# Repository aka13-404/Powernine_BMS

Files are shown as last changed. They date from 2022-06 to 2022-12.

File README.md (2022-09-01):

# Powernine BMS
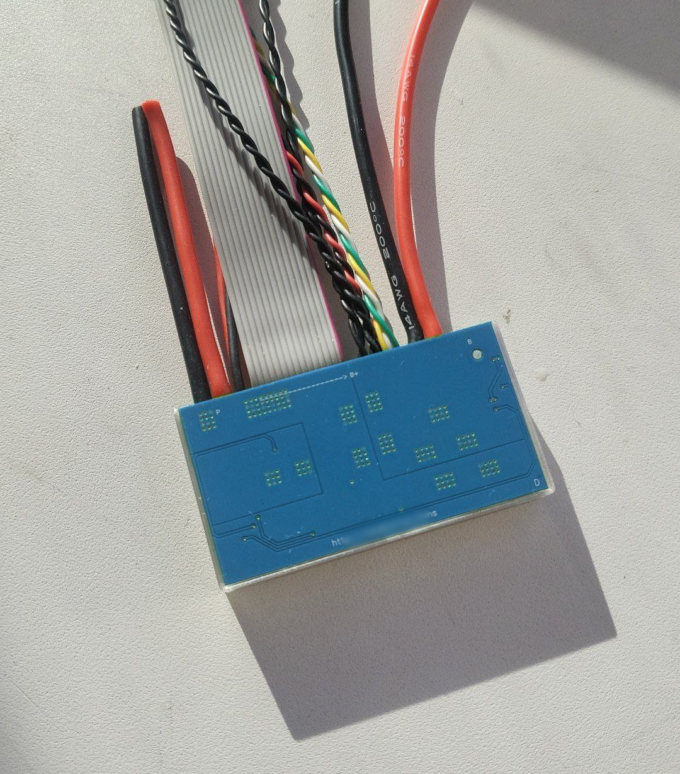
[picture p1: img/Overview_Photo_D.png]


This repository is dedicated to the documentation of the Powernine BMS project by SurgeSPB. 

The repository is split in two parts:
1. **[Hardware](Hardware)**
	The BMS is now out for a quite a long time, so multiple revisions exist. In this folder there are informations on individual parameters and differences of the different revisions and their parameters.
	It also contains information on what FW-versions are available
	**Never flash firmware other than noted**
2. **[Software](Software)**
	All existing BMS support configuration and firmware updating via bluetooth.
	The folder contains:
	  + The configuration tool used for the BMS, PowerNine
	  + Documentation on options available in Powernine, and how to use them
	  + Available firmwares to be used for different BMS revisions

## Features

_Current bms revision is **D**_.

|Parameter|Value|
| :--- |---:|
|Physical dimensions|65x35 mm|
|Peak discharge current|60 A|
|Max charge current|6 A|
|Cell balance current| 35 mA|
|Sections balanced at the same time | max 3|
|Balancing algorithm type|passive, 24/7 if no load is detected

This is a custom BMS, based on the stm G031 series. 
Its main feature is the **full support of the Ninebot/Xiaomi communication protocol**. 
It has a very small formfactor, and can deliver up to 60A peak current.
It's highly configurable, and can be configured according to the specific user scenario.
It is also possible to use it in stand-alone mode should you decide to ditch the ninebot ecosystem. 

## Where to buy

If you live in the eastern hemisphere, reach out directly to [Surge](https://t.me/SurgeSPB). 
If you live in Europe, reach out to [AK](https://t.me/aka13).

Please understand, that with current logistical limitations availability is limited and stock goes very quickly. 

## [Quick Setup](/Software/quick_setup.md)
There is a short manual on how to connect and setup the BMS, if you don't want to read the full documentation [here](/Software/quick_setup.md).

## Issues and questions

If you think something is missing/should be fixed in the documentation, or have suggestions, open an issue on github.

If you understand russian, want to discuss stuff, or get tips on the installation, you can join the [official group](https://t.me/ninebotfun). 
If you speak german or english, you can join the european group (coming soon).

## Disclaimer
Please remember, li-ion battaries are no joke. You should have an understanding on what you are doing, and why you are doing it. No BMS in the world is going to save you, if you don't know what you are doing.

Ride safe and obey local laws.

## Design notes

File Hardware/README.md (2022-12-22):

Please select the bms version you have/are interested in from the filelist on top.
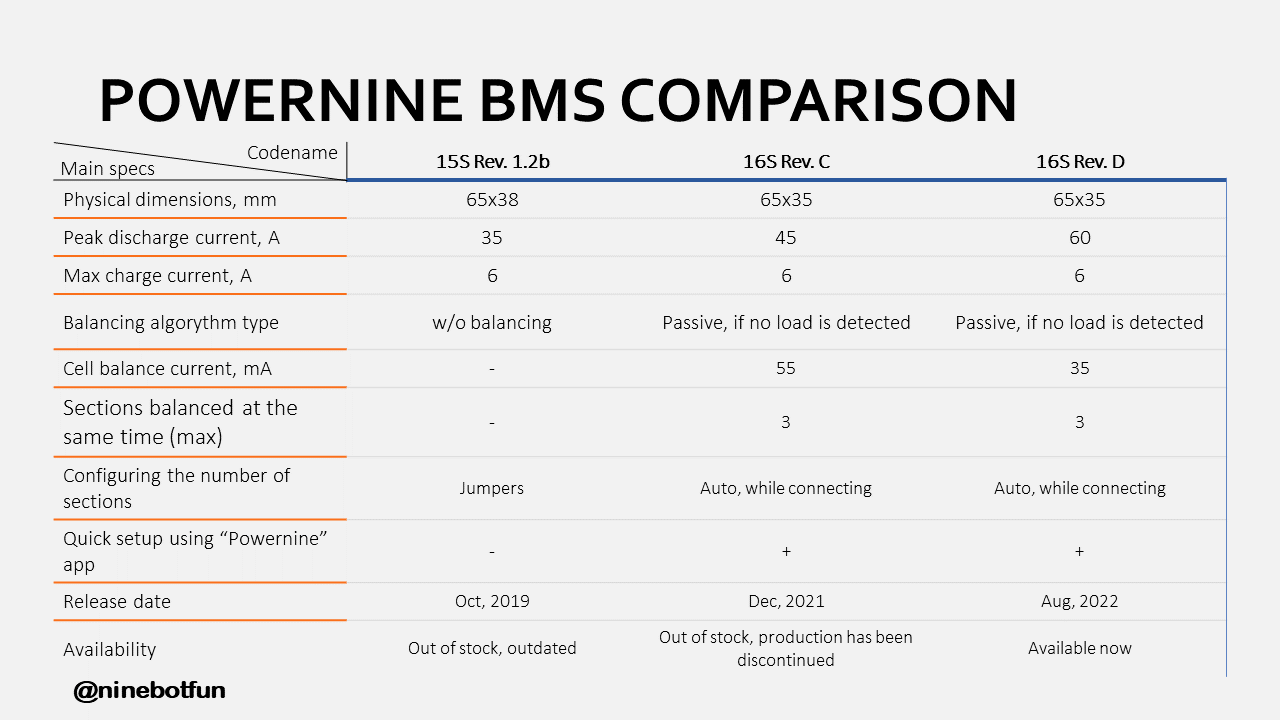
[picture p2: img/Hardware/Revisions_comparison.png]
Revision comparison


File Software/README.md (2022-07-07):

# Powernine configration manual
This document contains information on the available features, and their usage for the Powernine configuration application. Make sure, that you understand, what and why you change, before any changes. 

---
## 1. Info-Tab
This tab allows you to read currently saved/running parameters of your BMS.
On the top right you see the ESC and the BLE firmware versions.
On the top left you see your e-scooter name and the current mileage.
*If your scooter name is very short, mileage display may be bugged in the current version.*

The main scrollable window contains following fields:
|Field|Value|
|---|---|
|Serial number|The serial number of your ESC|
|Factory capacity|Configured battery capacity|
|Remaining capacity|Calculated remaining capacity of the battery. Remaining charge is multiplied by the configuted factory capacity.
|Accumulated charge| How much energy was pumped into the battery since the last cycle. This is calculated properly based on a coloumb counter and numerical integration of the current measurement. |
|Remaining charge| Remaining capacity in %, calculated from the set cell discharge curve and current pack voltage. The average voltage per cell is used for the calculation.|
|Charge count|Increments each time you charge the battery. Counts the number of times when voltage was detected on the charging port.|
|Charge cycles| Increments each time the accumulated charge is > factory capacity, so you can estimate the number of full cycles based on battery capacity.|
|Pack voltage| Pack voltage|
|Current draw| Current draw. Changes sign when charging/discharging.|
|Temperature #1| First battery thermistor. 10K 3930 NTC thermistors are used.|
|Temperature #2| Second battery thermistor. 10K 3930 NTC thermistors are used.|
|Voltage threshold|Max cell voltage difference in V|
|Cell voltage #X| Displays cell segment voltage. Also displays, which cell blocks (if any) are being balanced| 
---
## 2. Config-Tab
This tab allows you to adjust your BMS settings and get additional information.
**The values you set are applied automatically, when the bms goes into sleep mode. This happens after about 3-5 seconds after turning off the load.** The "Apply settings" button is depreciated and will be removed in future versions, does not do anything for the current revision. 
&nbsp;

### 2.1 "General" section
#### 2.1.1. Factory capacity
 You can set the capacity of your battery in mAh. To calculate the capacity, count the number of cells that you have in parallel (for example, 7p) and multiply it with the capacity that the individual cells have (for example, 3000mAh). 7P * 3000mAh = 21000 mAh.
 
#### 2.1.2. Power voltage
An additional debug metric to the pack voltage in the info tab.
*Depreciated, will be removed in future updates*

####  2.1.3. Charge voltage
An estimation of the voltage at the charging port. Useful for debugging issues with charging, and detecting damage to the charging port.

####  2.1.4. Frontend temp
The temperature of the main BMS chip, which is responsible for the heavy lifting when balancing. You may want to reduce the number of balanced cells if this gets too hot for your liking. 

####  2.1.5 Braking voltage
Ninebot escs can  disable the electronic brake, when issued a specific command, to not overload the battery. You can set a voltage (based on individual sections) over which no regenerative breaking is performed to extend the life of your battery.

&nbsp;
### 2.2 "Voltages" section
#### 2.2.1 Cell undervoltage
You can set a voltage (based on individual sections), below which the discharge fets will be disabled. Be careful, when adjusting this parameter, it should be lower, than your %-cutoff in the esc firmware, otherwise you might end up with the scooter suddenly turning off at an unexpected moment.
#### 2.2.2 Delay
You can set a time delay, which has to pass after reaching the trigger value, before undervoltage protection kicks in. Useful against battery sag, so that you don't fall into protection while accelerating at low voltages close to the cutoff.
#### 2.2.3 Recovery
You can set a delta recovery voltage after reaching the trigger value, after which the protection is disabled. Since battery voltage sags under load, this can and should be configured according to the health and sag of your battery. 
&nbsp;
#### 2.2.1 Cell overvoltage
You can set a voltage (based on individual sections), over which the charge fets will be disabled. 4,199 and lower is a safe value for any li-ion cell. 
#### 2.2.2 Delay
You can set a time delay, which has to pass after reaching the trigger value, before the overvoltage protection kicks in. 
#### 2.2.3 Recovery
You can set a delta recovery voltage, after which the protection is disabled. Since the voltage drops slightly after charge, this can and should be configured according to your charger and battery health.
&nbsp;
### 2.3 "Currents" sections
#### 2.3.1 Short circuit
This is the short-circuit protection current  of the BMS. It is recommended to set this current to 5x of your maximum rated current for the battery. Example: If you have cells, which can do 10A per cell, and you have 5 cells in parallel, this would mean 10A*5P*5=250A. 
*The preview in the overview is currently bugged and always displays 80A, no matter what is configured.*
#### 2.3.2 Delay
You can set a time delay, which has to pass, before the short-circuit overcurrent protection kicks in.
#### 2.3.3 Recovery
You can set a minimum time after reaching the trigger value, before the protection is disabled. 
#### 2.3.4 Max charge current
You can limit the charging current, if needed. 8A is the limit for the current revision.
#### 2.3.5 Delay
You can set a time delay, which has to pass after reaching the trigger value, before the overcurrent charging protection kicks in.
&nbsp;
### 2.4 "Temperatures" sections
#### 2.4.1 Overtemp charge
You can set the maximum temperature, over which **charge** FETs are disabled. Most li-ion batteries should not be charged when warmer than 45C. Please set this protection in accordance with your battery. 
#### 2.4.2 Delay
You can set a time delay, which has to pass after reaching the trigger value, before the overtemp protection kicks in.
#### 2.4.3 Recovery
You can set a minimum temperature the battery has to cool down to, before the overtemp protection is disabled. This should be set about 3-5C lower than the 'overtemp charge' parameter to avoid issues.
#### 2.4.4 Overtemp discharge
You can set the maximum temperature, over which **discharge** FETs are disabled. Most li-ion batteries should not be discharged when warmer than 60C. Please set this protection in accordance with your battery. The hotter the battery, the faster it degrades.
#### 2.4.5 Delay
You can set a time delay, which has to pass after reaching the trigger value, before the overtemp protection kicks in.
#### 2.4.6 Recovery
You can set a minimum temperature the battery has to cool down to, before the overtemp protection is disabled. This should be set about 3-5C lower than the 'overtemp charge' parameter to avoid issues.
&nbsp;
#### 2.4.7 Undertemp charge
You can set the minimum temperature, under which **charge** FETs are disabled. Li-ion batteries **can not be charged under 0C**. It causes Lithium plating of contacts and causes significant additional risks towars fires and explosions. 
#### 2.4.8 Delay
You can set a time delay, which has to pass after reaching the trigger value, before the undertemp protection kicks in.
#### 2.4.9 Recovery
You can set a minimum temperature the battery has to reach, before the undertemp protection is disabled. This should be set about 2-3C higher than the 'undertemp charge' parameter to avoid issues.
#### 2.4.10 Undertemp discharge
You can set the minimum temperature, under which **discharge** FETs are disabled. Most Li-ion batteries can not be discharged when under -20C, and **operation under 0C should be avoided**. 
#### 2.4.11 Delay
You can set a time delay, which has to pass after reaching the trigger value, before the undertemp protection kicks in.
#### 2.4.12 Recovery
You can set a minimum temperature the battery has to reach, before the undertemp protection is disabled. This should be set about 2-3C higher than the 'undertemp charge' parameter to avoid issues.
&nbsp;
### "State of charge" section
#### Cell resistance
You need to set the cell resistance for your battery sections, **this is important for battery SoC calculation**, otherwise your SoC will mean nothing and jump around due to voltage drops and not compensating for EMF. Here is how to calculate it: 
1. Measure or estimate your cell ACIR(internal resistance) based on the manufacturers spec. Should be usually <30 mOhm, even if you have reclaimed cells. Cells connected in parallel should have about the same ACIR.
2. Calculate the total resistance of the section by applying Kirchhoffs law for parallel currents. 
Example: You have 6 cells in parallel, they have on average 25mOhm resistance.
25/6=4,1=approx 4 mOhm. 

#### Discharge curve
You can adjust the voltage-discharge curve of your battery. Refer to the manufacturers specs if you want to adjust this. Can be useful for better SoC estimation. 
&nbsp;

### "Balancing" section
#### Min cell voltage
The balancing is passive - this means, cells, which are over the set balancing threshold get discharged, and their energy is "wasted". This means, you may want to limit the voltage, under which no balancing is performed. It is more than sufficient to balance after your normal charging process with voltage over 4.05-4.1, but depending on the age, health and disbalance of the battery, you may want to go lower or higher.

#### Balancing threshold 
You can set a minimal cell difference between sections, below which no balancing is performed. The less voltage difference between cells, the better, but depending on battary age and health you may want to go higher or lower.

#### Cell count
This determines, how many sections can be balanced at the same time. Due to passive balancing, more sections balanced - more heat on the bms. Depending on the heat you see on the bms in 2.1.4 and the season/weather you may want to go up or down with this value. You can balance up to 3 sections at the same time, adjanced sections are not balanced at the same time, to avoid overheating the bms. You can see which sections are getting balanced in the info tab of the app. The bms accounts for voltage sag when balancing.
&nbsp;

### "Blackbox" section
#### Latest overvoltage snapshot
When overvolage protection is triggered, you can check here, what specifically was the cause for the trigger and the cell state at that moment.

#### Latest undervoltage snapshot
When undervoltage protection is triggered, you can check here, what specifically was the cause for the trigger and the cell state at that moment.

#### Connected cells
You can check here, if all sections are connected properly. If you don't see a section here, which is supposed to be there, you have a mechanical connection problem.

#### Check for updates
Depreciated, will be removed in future versions. Does not do anything.

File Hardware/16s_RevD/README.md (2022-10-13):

# 16S BMS Revision D

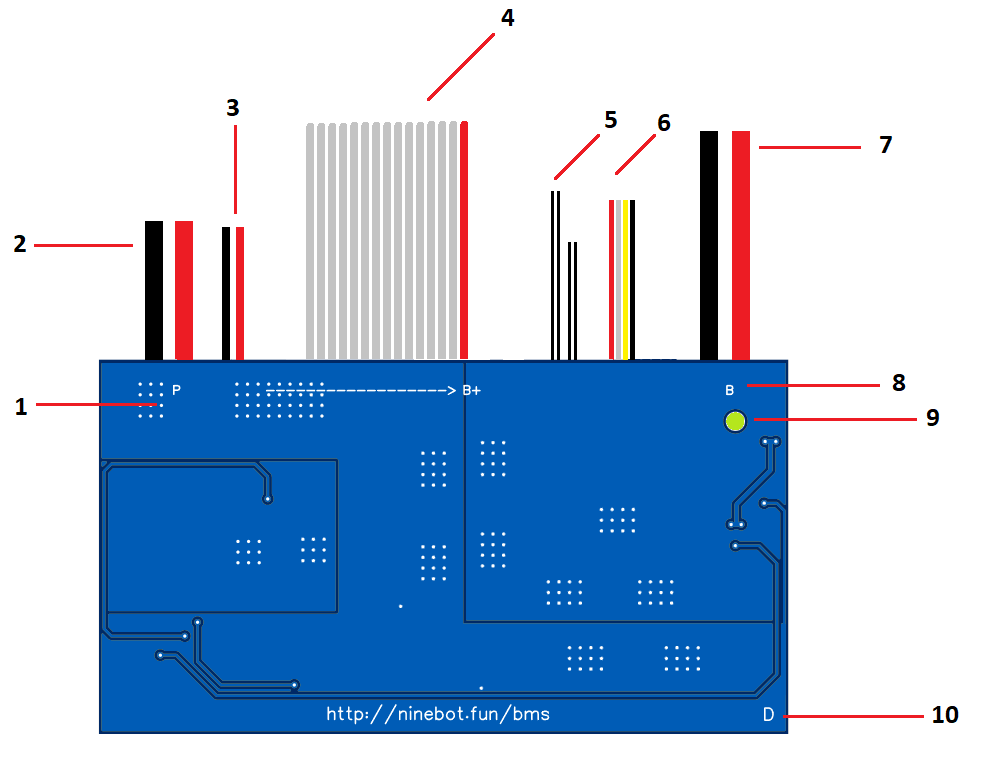
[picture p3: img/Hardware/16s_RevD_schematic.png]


**Latest firmware is 716.**
Download it from the filelist above.
Firmware flashing is done with XIAOFLASHER.

## Connections 
1. Power section (XT60 or XT30 goes here)
2. Power positive / power negative (towards the ESC)
3. Charging wires
4. Balancing connector
5. Thermistors
6. Data connection to the ESC
7. Battery positive / battery negative (towards battery)
8. Battery section
9. LED status indicator
10. Revision marker 

The BMS comes **fully pre-wired** with stock ninebot DC charger connector. The **stock connector to the charger port MELTS when charging over 4A**. If you plan charging with higher currents, change the connector.

Please consider the fact, that when running 60A through the BMS, the discharge mosfets dissipate about 4W of heat, which needs to be moved away from the BMS. Attach a heatsink from the bms to the frame to prevent failure through mosfet overheating. 

## Parameters

This revision has the following parameters:
|Parameter|Value|
| :--- |---:|
|Physical dimensions|65x35 mm|
|Peak discharge current|60 A|
|Max charge current|6 A|
|Cell balance current| 35 mA|
|Sections balanced at the same time | max 3|
|Balancing algorithm type|passive, 24/7 if no load is detected

## Connecting

1. Attach bms with holder securely to the battery. Make sure that no part of the BMS touches metal.
2. Attach battery ground (thick black wire under B section). 
3. Attach balancing wires in correct order. 
Balancing wires start from B1. After you have connected the B4 cable, the bms will be on and in the configuration mode, indicated by blinking of the red and green LEDs in sequence. Ignore the LEDs until the B4 is connected.
If connecting less than 16 sections, you start with battery ground, and connect the sections until the the second to last one. The unused wire are connected together on the BMS, and the last section is connected to battery positive.
**Consult the diagram for you convenience**
4. Attach battery positive (thick red wire under B section). The BMS will automatically exit the setup mode and start blinking with the green LED. If it is not blinking, then you made a mistake while connecting the cables, and the sections were not recognized. You need to repeat the connection process.

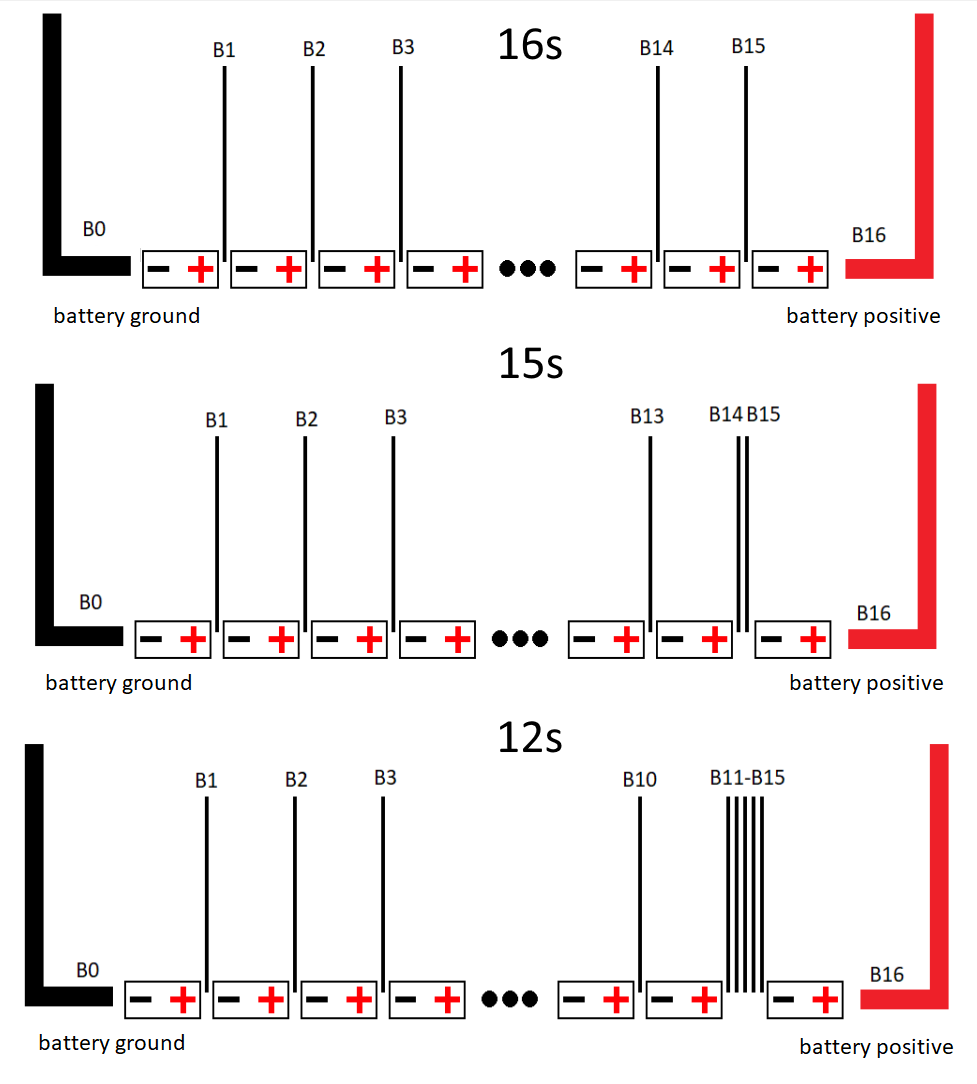
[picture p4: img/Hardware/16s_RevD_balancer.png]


## Troubleshooting

If you do not have bluetooth access via the BLE/ESC, you can read out some error codes based on the LEDs on the BMS itself. The blinking only happens, when no load is attached to the battery (scooter is turned off)

Following Error Codes are available:

|LED Status|Meaning|
| :--- |---:|
|Red and green blinkinng in sequence| Configuration mode, the BMS waits for sections attechment|
|Red and green constantly on| Firmware update mode. Happens, if the wrong firmware was flashed, or if the flashing was interrupted. Will remain in this mode until firmware is flashed properly. You can also detect this mode by the battery serial number being detected as "UPLOAD MODE" and charge remaining at 5%. BMS can not be configured in this mode.|
|Green flashing quickly, every 2s|Normal standby mode|
|Green flashing slowly| Working mode, load is detected|
|Green on | One or more sections have reached charging cutoff |
|Red on| One or more sections have reached discharge cutoff |
|Red flashing slowly| Charging current detected, battery is charging|
|Red flashing quickly, 2 times| Charging current is too big|
|Red flashing quickly, 3 times| Short circuit or discharge current too high|
|Red flashing quickly, 4 times| Overtemp protection enabled|
|Red flashing quickly, 5 times| Undertemp protection enabled|

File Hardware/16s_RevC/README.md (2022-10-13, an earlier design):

# 16S BMS Revision C

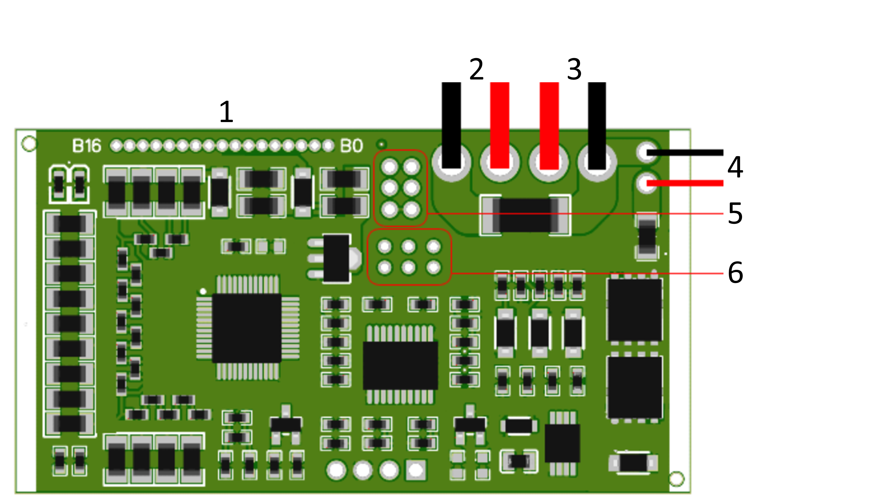
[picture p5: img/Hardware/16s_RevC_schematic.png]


**Latest firmware is 711.**
Download it from the filelist above.
Firmware flashing is done with XIAOFLASHER.

## Connections 
1. Balancer connector
2. Battery connection
3. Load connection (to the ESC)
4. To charger
5. Data connection to the ESC
6. Thermistors 

The BMS comes **pre-wired** for the stock ninebot DC charger connector. The **stock connector to the charger port MELTS when charging over 4,5A**. If you plan charging with higher currents, change the connector.

Please consider the fact, that when running 60A through the BMS, the discharge mosfets dissipate about 4W of heat, which needs to be moved away from the BMS. Attach a heatsink from the bms to the frame to prevent failure through mosfet overheating. 

## Parameters

This revision has the following parameters:
|Parameter|Value|
| :--- |---:|
|Physical dimensions|65x35 mm|
|Peak discharge current|60 A|
|Max charge current|6 A|
|Cell balance current| 55 mA|
|Sections balanced at the same time | max 3|
|Balancing algorithm type|passive, 24/7 if no load is detected

## Connecting

1. Attach power and charge wiring of desired length to the BMS. If needed, replace the charging connector.
2. Place the BMS in a printed holder, or attack it securely to the battery. Make sure that no part of the BMS touches metal. You can use one of the available holders from [here](/stl).
3. Attach balancing wires in correct order. 
**You MUST start with the B0** Or the negative load cable. After you have connected the B4 cable, the bms will be on and in the configuration mode, indicated by blinking of the red and green LEDs in sequence. Ignore the LEDs until the B4 is connected.
4. After connecting the remaining wires (**B16 or positive load cable MUST be last**) the BMS will automatically exit the setup mode and start blinking with the green LED. If it is not blinking, then you made a mistake while connecting the cables, and the sections were not recognized. You need to repeat the connection process.
5. If connecting less than 16 sections, you start with the B0, and connect the sections until the the second to last one. The unused wire are connected together on the BMS, and the last section is connected to B16. See the picture below for better understanding.

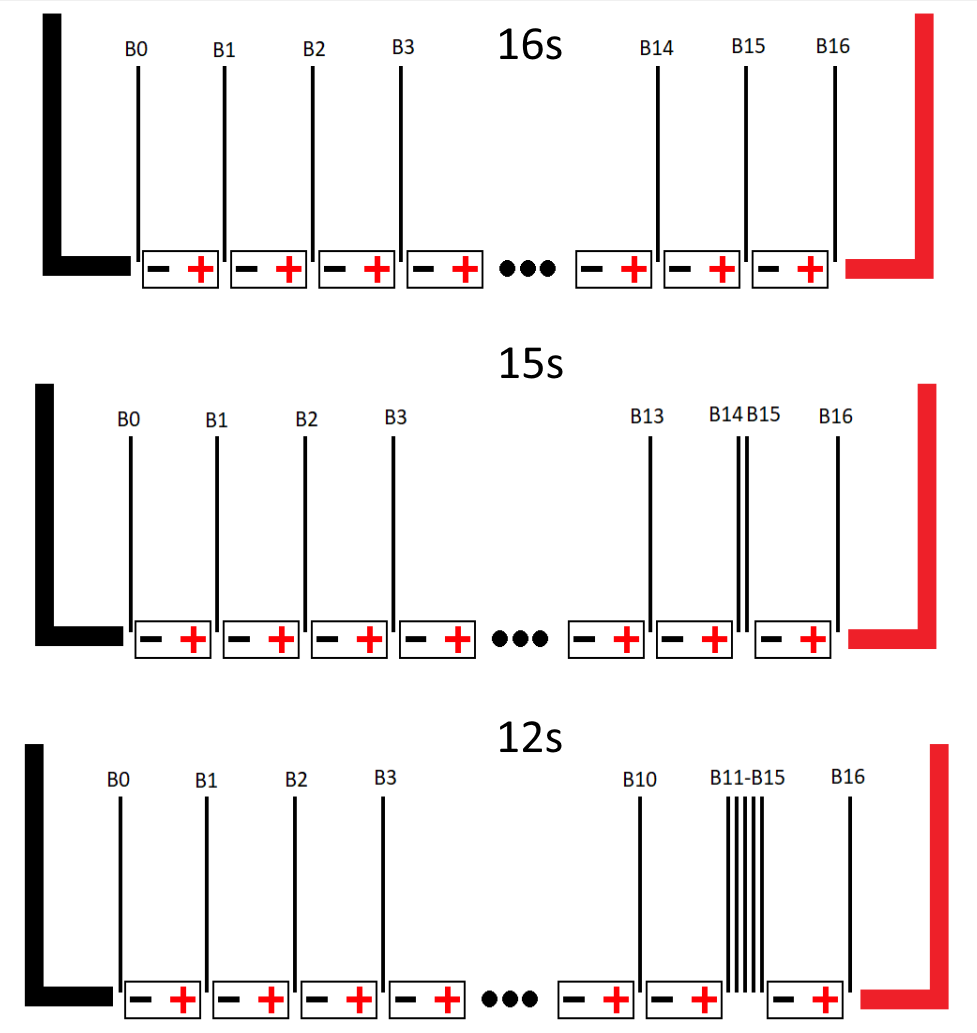
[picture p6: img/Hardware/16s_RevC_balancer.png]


## Troubleshooting

If you do not have bluetooth access via the BLE/ESC, you can read out some error codes based on the LEDs on the BMS itself. The blinking only happens, when no load is attached to the battery (scooter is turned off)

Following Error Codes are available:

|LED Status|Meaning|
| :--- |---:|
|Red and green blinkinng in sequence| Configuration mode, the BMS waits for sections attechment|
|Red and green constantly on| Firmware update mode. Happens, if the wrong firmware was flashed, or if the flashing was interrupted. Will remain in this mode until firmware is flashed properly. You can also detect this mode by the battery serial number being detected as "UPLOAD MODE" and charge remaining at 5%. BMS can not be configured in this mode.|
|Green flashing quickly, every 2s|Normal standby mode|
|Green flashing slowly| Working mode, load is detected|
|Green on | One or more sections have reached charging cutoff |
|Red on| One or more sections have reached discharge cutoff |
|Red flashing slowly| Charging current detected, battery is charging|
|Red flashing quickly, 2 times| Charging current is too big|
|Red flashing quickly, 3 times| Short circuit or discharge current too high|
|Red flashing quickly, 4 times| Overtemp protection enabled|
|Red flashing quickly, 5 times| Undertemp protection enabled|

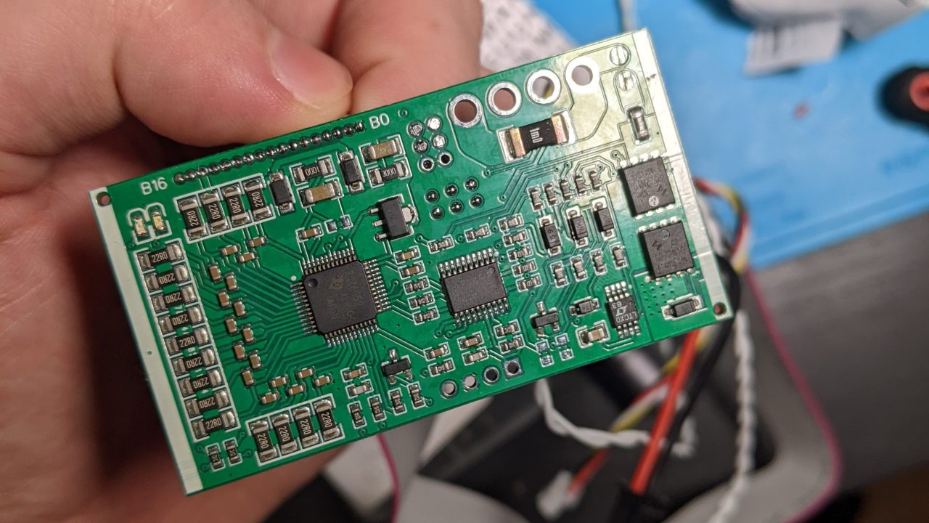
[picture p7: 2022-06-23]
img/Overview_Photo.png

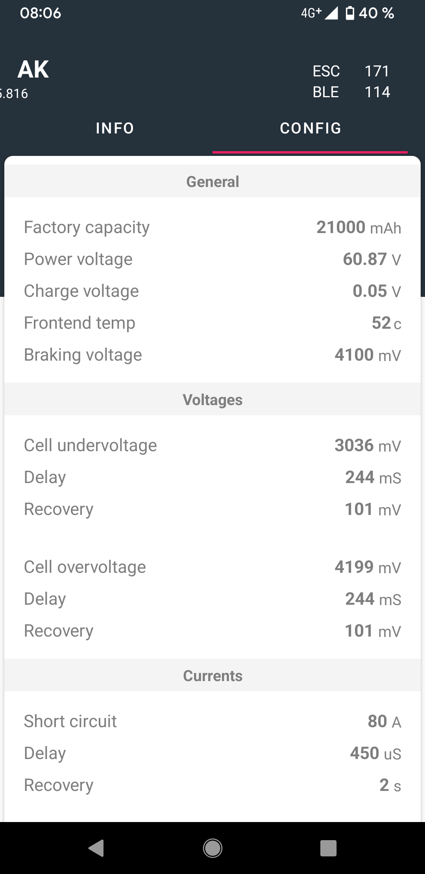
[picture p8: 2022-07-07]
img/Powernine_Interface/Config_1.png

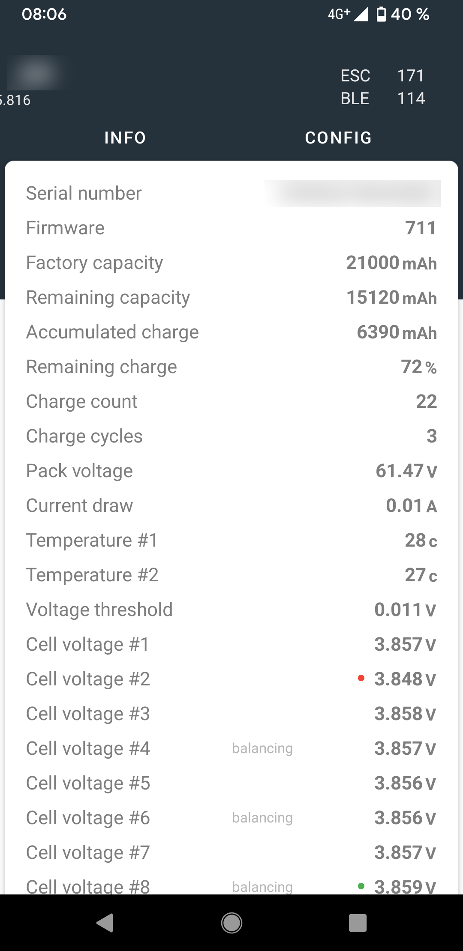
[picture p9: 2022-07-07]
img/Powernine_Interface/Info_1.png

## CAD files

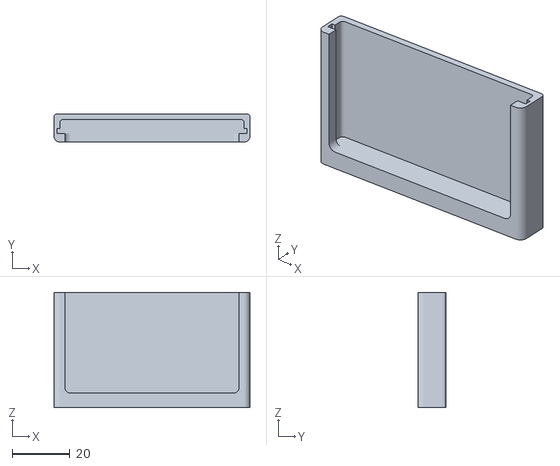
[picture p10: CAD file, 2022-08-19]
stl/RevC_generic_holder.stl
68.0 x 9.80 x 40.0

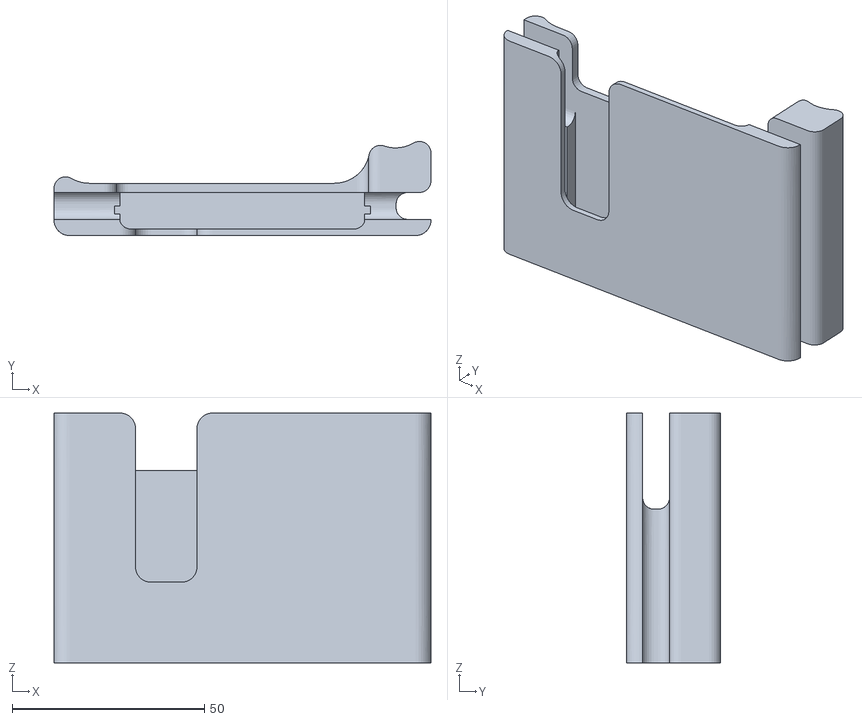
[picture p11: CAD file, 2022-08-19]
stl/ReC_G30_120cells_holder.stl
98.1 x 24.5 x 65.0

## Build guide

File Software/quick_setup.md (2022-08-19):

# Quick setup 

1. Connect your BMS to your battery according to your revisions manual [here](/Hardware/). The revision is noted on the lower right corner of the PCB. Current revision number is [D](/Hardware/16s_RevD.md).
2. Update your firmware. Use xiaoflasher to flash the latest BMS firmware. Firmware can be found in the [software](/Software/) folder.
   1. Open xiaoflash, connect to your scooter
   2. Select the .zip and press flash. Ignore the warnings, that this firmware is for another scooter
   3. Wait for flashing to finish
3. Enter the correct capacity of your battery in the config, [factory capacity option](/Software/README.md#211-factory-capacity) Use the capacity of a cell, multiply it with how many cells you have in parallel. Example: For a 16s5p battery with 3000 mAh cells: 3000mAh * 5P = 15000mAh.
4. Set [short-circuit current](/Software/README.md#231-short-circuit) to 5x your rated battery current. For a 16s5P battery, with cells that support 10A max: 10A * 5P * 5 = 250A.
5. Set [section resistance](/Software/README.md#cell-resistance). If you know your cells internal resistance, use it. If you don't know it, use the one from the datasheet. If your cells fell of the back of a truck, assume internal resistance at 30mOhm. For a 16s5p battery with 30mOhm cells: 30mOhm/5P = 6mOhm.
6. Let the battery charge and balance the sections out. 
7. Don't skip steps, otherwise you will have bad battery data and wrong current cutoffs.

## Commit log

2022-07-07 Base powernine apk review
2022-10-13 Change file structure for board revisions
2023-02-02 Rev D - firmware v718
    - Improved current measurement accuracy
    - Improved SOC calculation ( two more stages )
    - Improved general flow of code
    - BMS now blinks twice in sleep mode while balancing battery
    - Fixed UTD error
    - Added param mask support for external apps
    - Added min stack voltage safety trigger
    - Improved temperature readings handling
